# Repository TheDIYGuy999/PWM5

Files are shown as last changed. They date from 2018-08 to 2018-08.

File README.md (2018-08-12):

# This is an Arduino "PWM5" Solar Charge Controller

It was originally invented by Julian Ilett: https://www.youtube.com/watch?v=AobcNhLG_Xw&list=PLjzGSu1yGFjWa5BEHgX5UUrSexppett3W

This Arduino version uses a similar layout as arduined.eu: https://www.arduined.eu/arduino-solar-charge-controller/

After I designed and built a couple of own MPPT solar chargers (see my other Repositories here), I wanted to try this "classic" PWM design.
It works fine, but of course you can't use it for nominal voltages below 12V (or at least it would be very inefficient in this case). Check out the included PCB files, if you want to build your own PWM5 controller.

## Features / Improvements:
- Programmable with Arduino IDE
- Input voltage 12 - 22V (36 cell solar panel)
- Output voltage 10.8 - 14.4V (6 cell 12V lead acid battery)
- Suitable for solar palels up to 100W (according to Julian Ilett)
- Using the 3.3V, 8MHz Arduino Pro Mini, which requires about 5mA (instead of 20mA for the 5V, 16MHz version)
- IRLZ44N logic level MOSFET used, because the charge pump can't deliver enough voltage with 3.3V supply
- Working frequencies: 15kHz (charge pump), 2kHz (PWM)
- Structurized the software, added serial output, improved the LED to be similar with Julians design
- Readings and calculations are based on vcc, which is read automatically
- Much simpler differential control algorithm
- Schematic better structurized, easier to understand
- Minor component value changes
- Eagle schematic and board file available
- Gerber files available (allows you to order your own boards easily)
- This controller is COMMON NEGATIVE
- An anti backfeed diode on the solar panel side is required

New in V 1.0:
- Initial commit, tested with my 10W and 20W solar panels, charging my 12V, 6.6Ah Lead Acid Gel battery

## Usage

See pictures
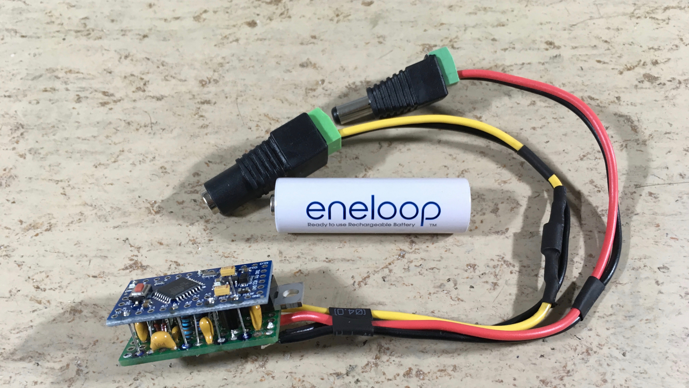
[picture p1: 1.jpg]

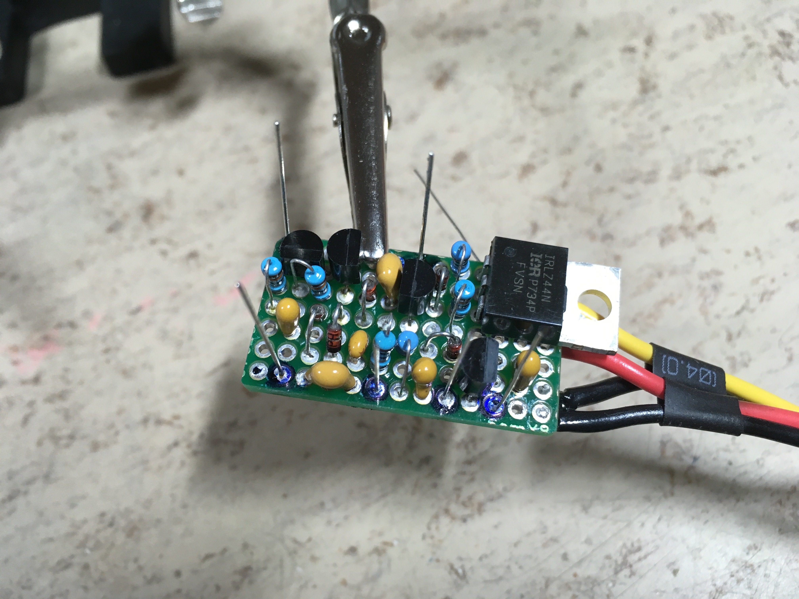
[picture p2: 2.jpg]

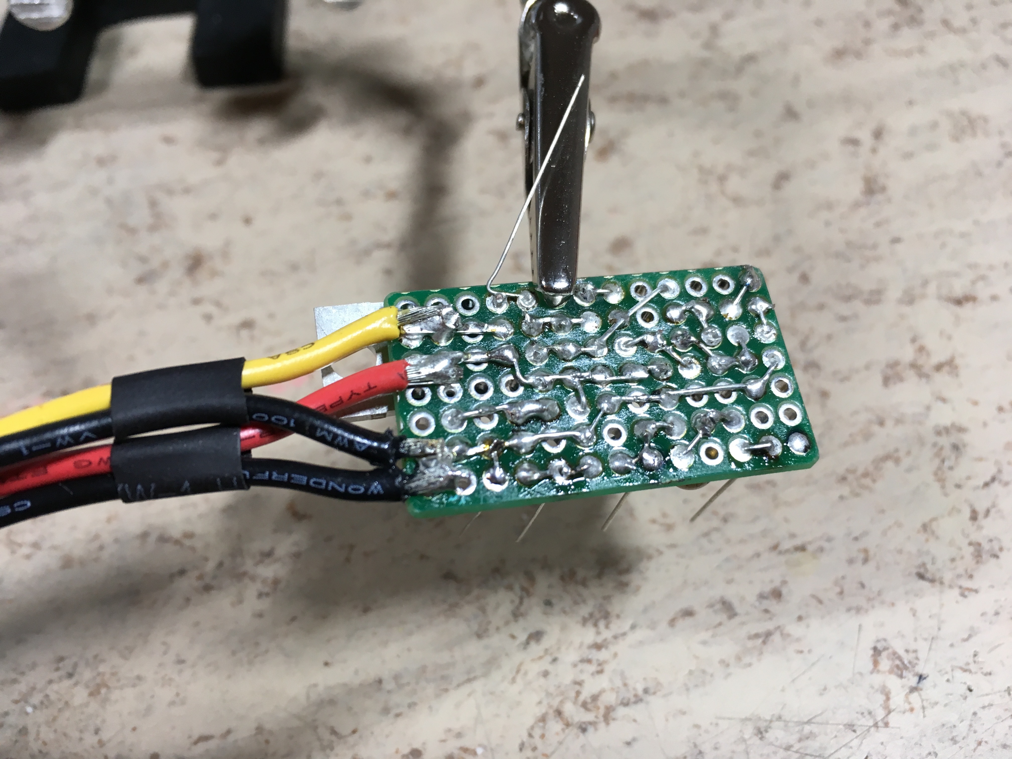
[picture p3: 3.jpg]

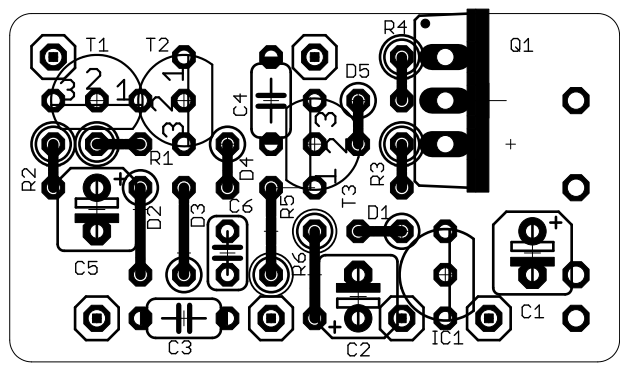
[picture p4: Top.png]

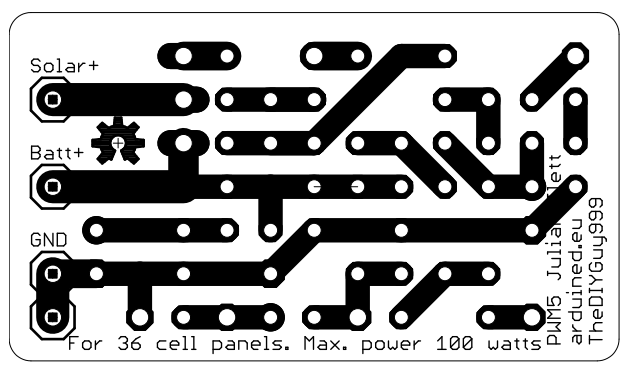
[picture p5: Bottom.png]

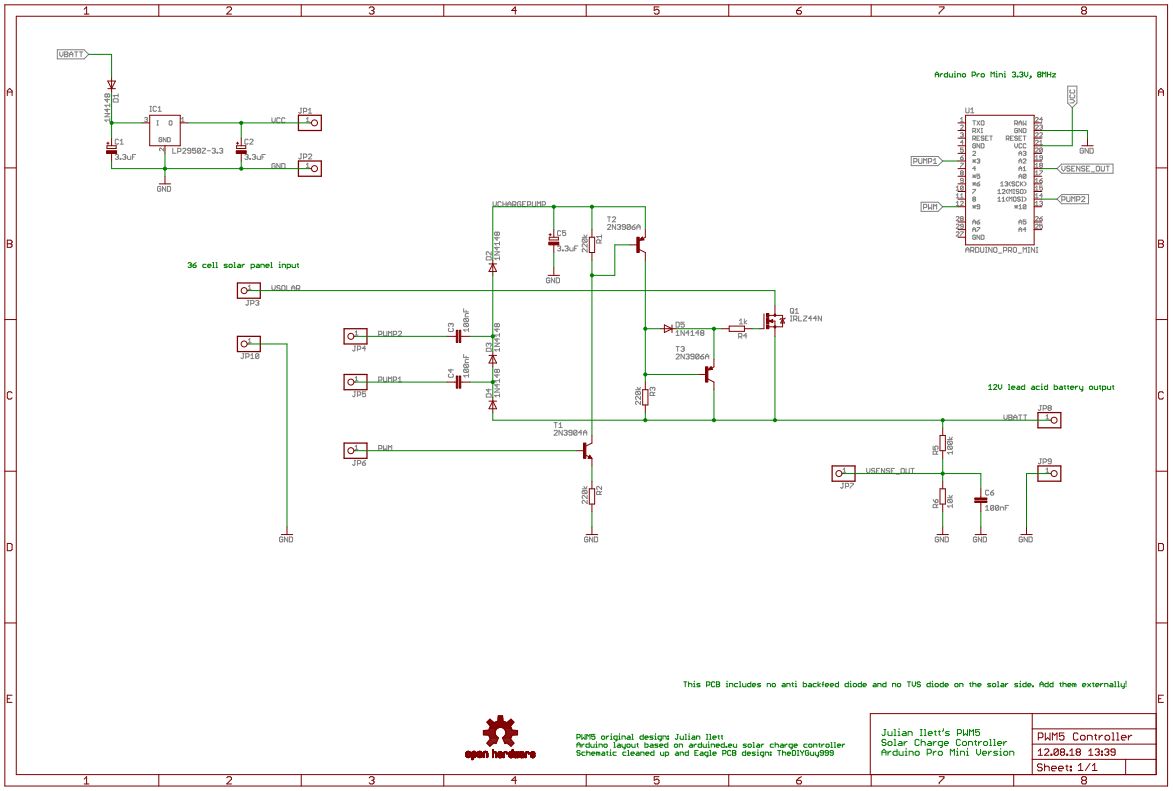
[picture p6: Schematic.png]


Also have a look at the pdf schematic.

(c) 2018 TheDIYGuy999

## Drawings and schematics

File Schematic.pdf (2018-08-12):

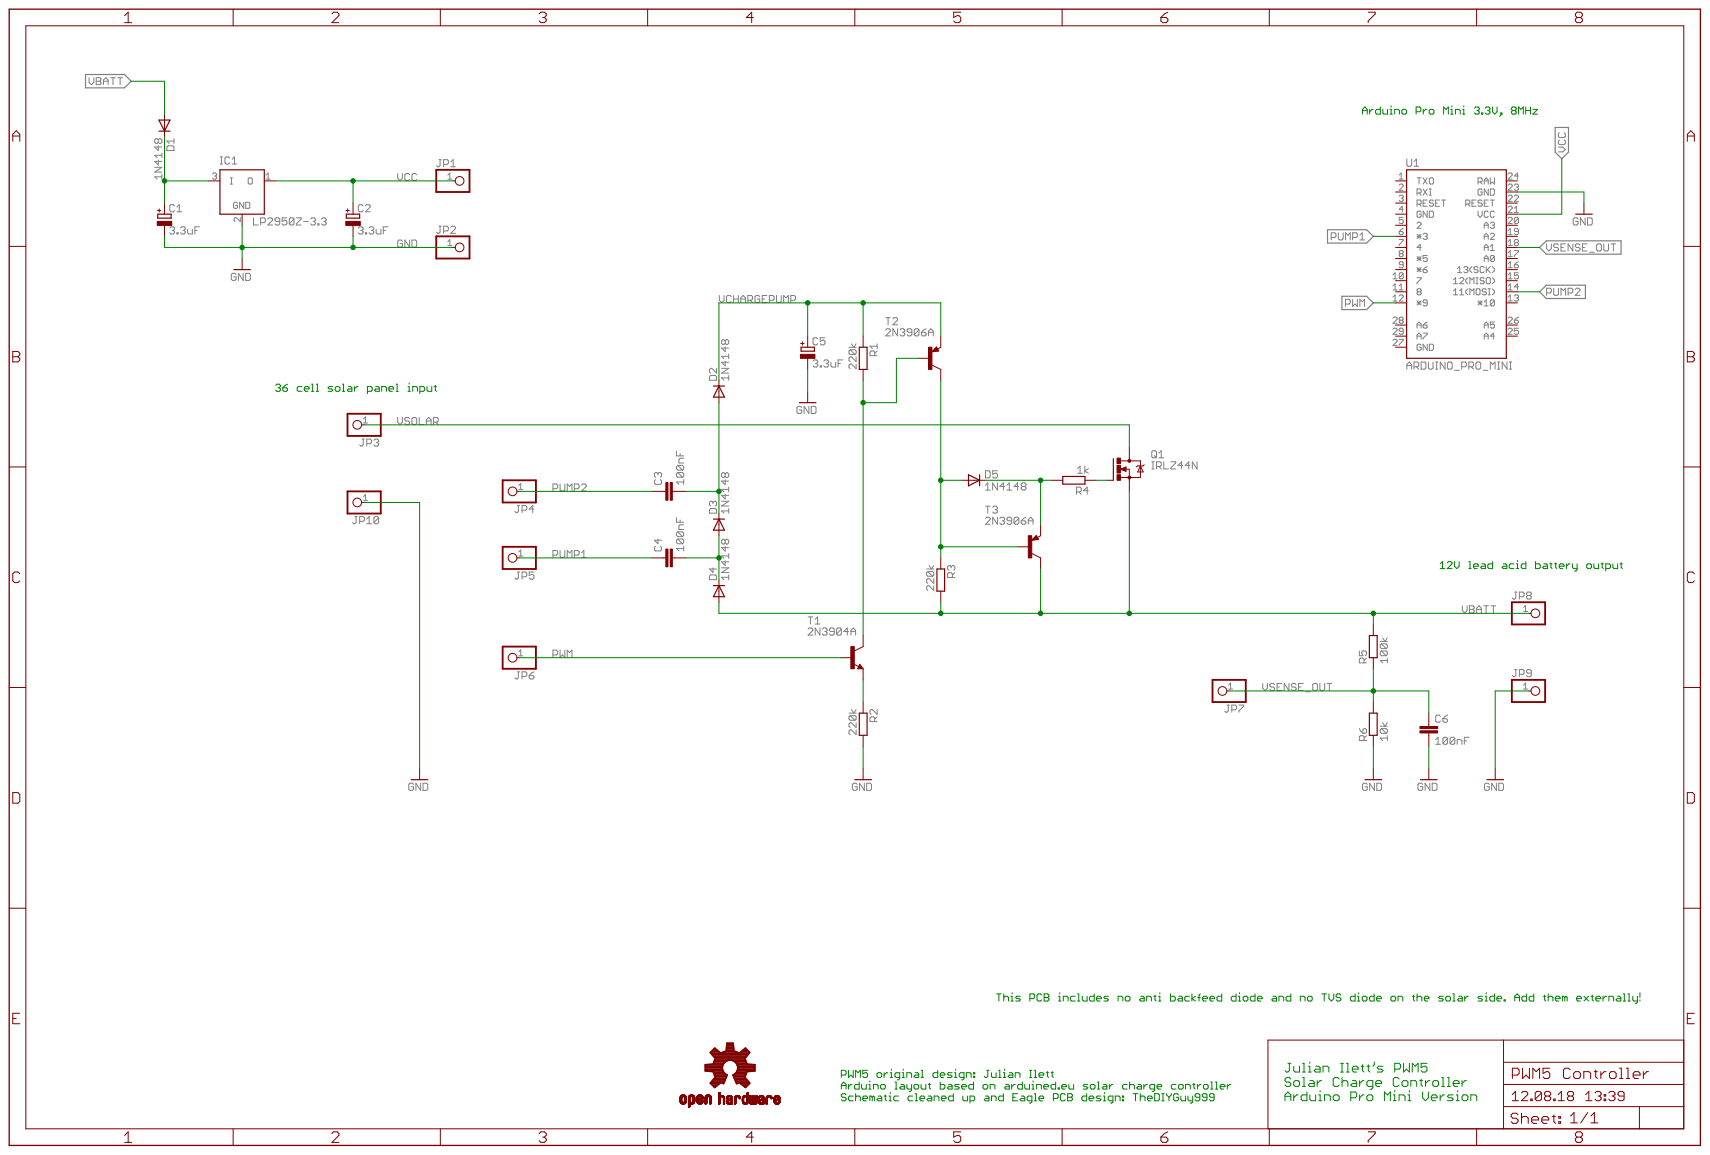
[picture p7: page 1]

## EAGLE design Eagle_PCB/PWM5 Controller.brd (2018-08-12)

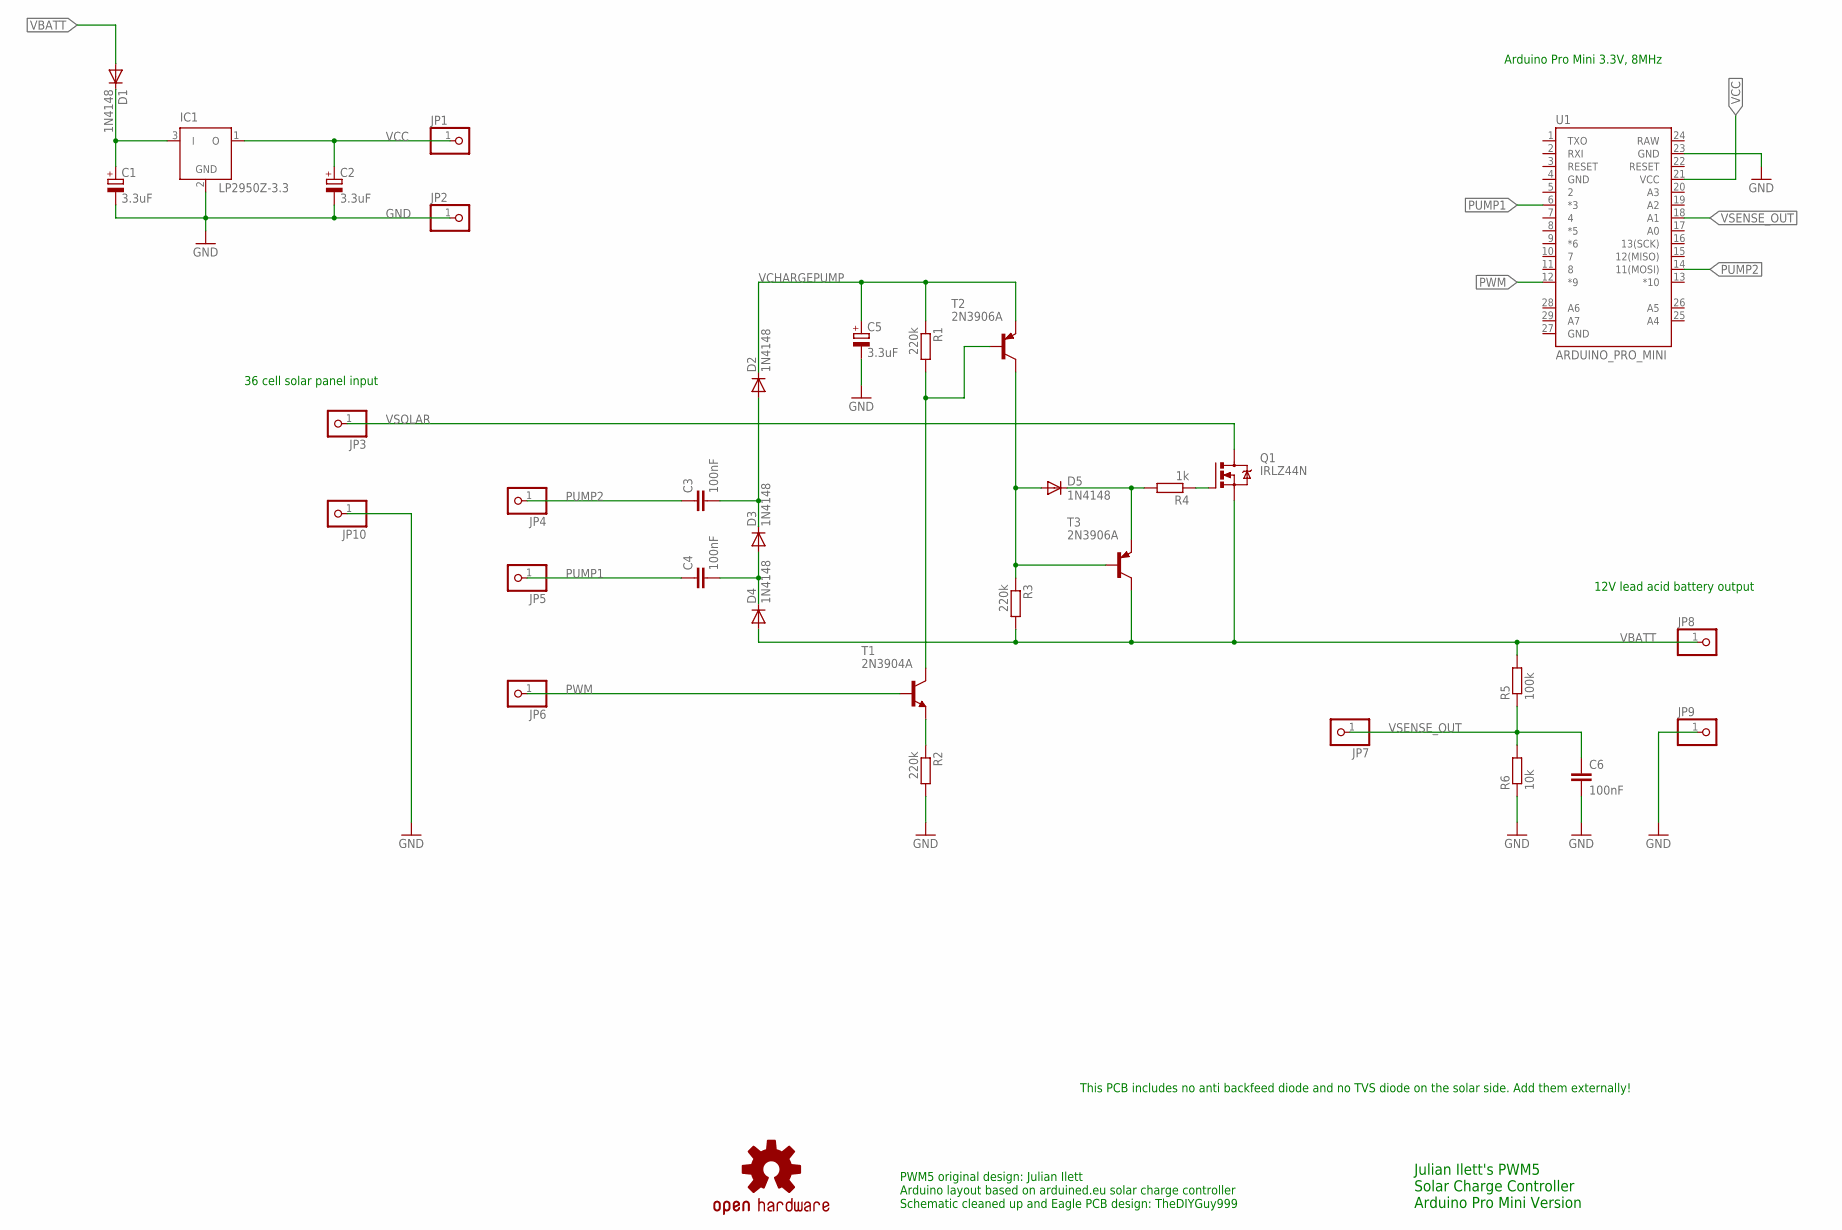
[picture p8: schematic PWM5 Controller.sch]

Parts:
C1, C2, C5: 3.3uF; B45181A
C3, C4: 100nF; C050-024X044
C6: 100nF; C025-024X044
D1, D4, D5: 1N4148; DO35-V
D2, D3: 1N4148; DO35-V2
IC1: LP2950Z-3.3; TO92-AMMOPACK
JP1, JP2, JP3, JP4, JP5, JP6, JP7, JP8, JP9, JP10: PINHD-1X1; 1X01
LOGO1: OSHW-LOGOS; OSHW-LOGO-S
Q1: IRLZ44N; TO220BV
R1, R2, R3: 220k; 0207/2V
R4: 1k; 0207/2V
R5: 100k; 0207/5V
R6: 10k; 0207/5V
T1: 2N3904A; TO92-AMMOPACK
T2, T3: 2N3906A; TO92-AMMOPACK
U1: ARDUINO_PRO_MINI

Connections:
GND: C1.-, C2.-, C5.-, C6.2, IC1.2 (GND), JP2.1, JP9.1, JP10.1, R2.2, R6.1, U1.23 (GND)
unnamed: D5.C, R4.2, T3.3 (E)
unnamed: Q1.G, R4.1
unnamed: C1.+, D1.C, IC1.3 (I)
unnamed: R2.1, T1.3 (E)
unnamed: D5.A, R3.1, T2.1 (C), T3.2 (B)
unnamed: R1.2, T1.1 (C), T2.2 (B)
unnamed: C4.2, D3.A, D4.C
unnamed: C3.2, D2.A, D3.C
PUMP1: C4.1, JP5.1, U1.6 (*3)
PUMP2: C3.1, JP4.1, U1.14 (11(MOSI))
PWM: JP6.1, T1.2 (B), U1.12 (*9)
VBATT: D1.A, D4.A, JP8.1, Q1.S, R3.2, R5.2, T3.1 (C)
VCC: C2.+, IC1.1 (O), JP1.1, U1.21 (VCC)
VCHARGEPUMP: C5.+, D2.C, R1.1, T2.3 (E)
VSENSE_OUT: C6.1, JP7.1, R5.1, R6.2, U1.18 (A1)
VSOLAR: JP3.1, Q1.D

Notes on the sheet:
Julian Ilett's PWM5 Solar Charge Controller Arduino Pro Mini Version
PWM5 original design: Julian Ilett Arduino layout based on arduined.eu solar charge controller Schematic cleaned up and Eagle PCB design: TheDIYGuy999
This PCB includes no anti backfeed diode and no TVS diode on the solar side. Add them externally!
Arduino Pro Mini 3.3V, 8MHz
36 cell solar panel input
12V lead acid battery output

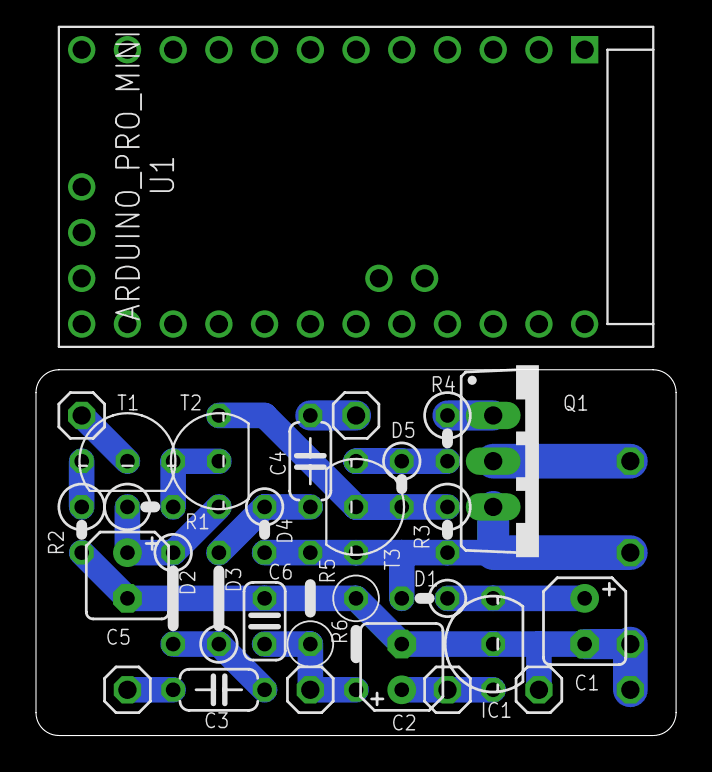
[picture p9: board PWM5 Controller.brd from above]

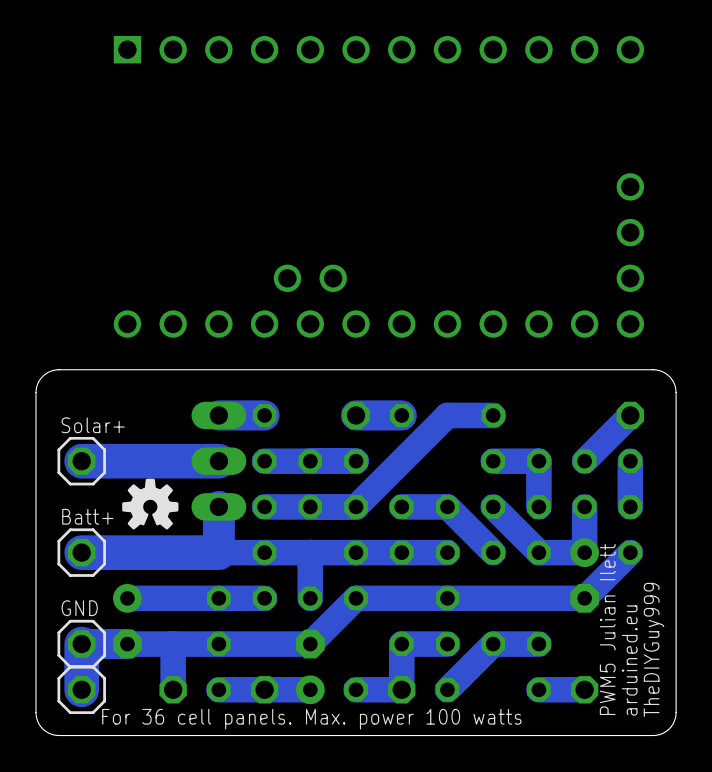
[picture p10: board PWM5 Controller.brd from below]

Board: 2 copper layers, 35.6 x 20.3 mm, 34 parts (5 on the bottom side), 17 nets.

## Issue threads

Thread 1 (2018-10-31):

Odd PWM Waveform on MOSFET Gate Pin

jmd13391, 2018-10-31:
Hi TheDIYGuy999 !! Thank you for your excellent work on this PWM5 variant. I have taken your design and attempted to adopt it for use with a 24v,18Ah battery and a 37v, 70w solar panel. Although I am using a different MCU, all discrete components are as you call-out in the original schematic with the exception of the voltage divider resistors R5 & R6 (47K, 5.6K) and C5 (10uF). Here is my question / issue:

I am seeing an odd "inverted shark fin" PWM waveform at the MOSFET gate and was hoping that you might have insight as to how to correct it. See photo. CH1 (yellow) is the PWM waveform from the MCU. CH2 (blue) is the PWM waveform at the MOSFET gate.

MCU PWM Freq. = 300Hz. (MCU max is 1KHz.)
MCU Charge Pump Freq: 4.14KHz. (this is the MCU max)

Thank you in advance...

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

TheDIYGuy999, 2018-10-31:
Hi,
Looks like the mosfet gate is not discharged fast enough. This is a potential issue of Julians gate driver circuitry. T3 provides a fast discharge path, but does not work at low voltages, because of the D5 voltage drop. That's why the voltage starts dropping fast and then slow.
The charge pump frequency may also be too low for a stable gate supply. Have you confirmed the stability of this rail with the scope? I assume, you have used a bigger C5 because of this potential issue.
Also make sure, that you don't exceed the gate and base voltage limits of your transistors, because of your high voltages.

jmd13391, 2018-10-31:
Hi TheDIYGuy999, Thank you for your prompt reply.

> "T3 provides a fast discharge path, but does not work at low voltages, because of the D5 voltage drop."

Would replacing D5 (1N4148) with a lower voltage drop Schottky diode improve the discharge rate?

> "The charge pump frequency may also be too low for a stable gate supply."

I had a typo in my original post... the Charge Pump pulse frequency of each square wave is ~4.14Khz., CP1 pulse & CP2 pulse waves are 180 degrees out of phase with a 10uS state change delay:

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

> "Have you confirmed the stability of this rail with the scope?"

Yes. Rock solid at 29.1v under the following conditions - Battery: 26.81v, Solar Panel: 33.52v

> "I assume, you have used a bigger C5 because of this potential issue."

Yes, Sir. ;-)

Do you have any suggestions as to how the circuit can be modified so as to improve the trailing edge of the MOSFET gate pulse?

Thank you again for your assistance with this issue...

jmd13391, 2018-11-13:
Closing due to inactivity.

Closed 2018-11-13.

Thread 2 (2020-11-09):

Board size for Gerbers.zip? JLPCB asks that :-7

Meins321, 2020-11-09:
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
JLPCB asks for the board size of the gerber files...

BTW to you have one or two boards? i would like to build one and try charging a 12V lead acid with it :+1:

TheDIYGuy999, 2020-11-11:
You don't need to add the size, just upload the updated Gerbers.zip. Then it should look like this:
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

No, I don't have boards, I just made one on veröffentlicht board

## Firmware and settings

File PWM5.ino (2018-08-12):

/* This PWM solar charge controller is based on:
    Julian Itett's PWM5: https://www.youtube.com/watch?v=AobcNhLG_Xw&list=PLjzGSu1yGFjWa5BEHgX5UUrSexppett3W
    arduined.eu's PWM solar charge controller: https://www.arduined.eu/arduino-solar-charge-controller/

    Changes and improvements, implemented by TheDIYGuy999:
    - Using the 3.3V, 8MHz Arduino Pro Mini, which requires about 5mA (instead of 20mA for the 5V, 16MHz version)
    - IRLZ44N logic level MOSFET used, because the charge pump can't deliver enough voltage with 3.3V supply
    - Structurized the software, added serial output, improved the LED to be similar with Julians design
    - Readings and calculations are based on vcc, which is read automatically
    - Much simpler differential control algorithm
    - Schematic better structurized, easier to understand
    - Minor component value changes
    - Eagle schematic and board file available
    - Gerber files available (allows you to order your own boards easily)
*/

const float codeVersion = 1.0; // Software revision

//
// =======================================================================================================
// BUILD OPTIONS (comment out unneeded options)
// =======================================================================================================
//

#define DEBUG // if not commented out, Serial.print() is active! For debugging only!!

//
// =======================================================================================================
// INCLUDE LIRBARIES
// =======================================================================================================
//

// Tabs (header files in sketch directory)
#include "readVCC.h"

// Libraries
#include <statusLED.h> // TheDIYGuy999 library: https://github.com/TheDIYGuy999/statusLED

//
// =======================================================================================================
// PIN ASSIGNMENTS & GLOBAL VARIABLES
// =======================================================================================================
//

// Pins
#define PWM 9
#define PUMP1 3
#define PUMP2 11
#define VSENSE_OUT A1

// Status LED objects
statusLED LED(false); // false = not inversed (LED wired between GND and output)

float outputVoltage;
float vcc = 3.3; // Init value only. Will be read automatically later on. Base for all our voltage readings!
float pwm; // float required for finer granularity during calculation in differential equations!

// Configuration variables (you may have to change them)
float targetOutputVoltage = 13.8; // Our maximum battery charge voltage
float voltageCalibration = 94.7; // (100k + 10k) / 10k = 11  ->  1024 / 11 = 93.09 in theory

//
// =======================================================================================================
// MAIN ARDUINO SETUP (1x during startup)
// =======================================================================================================
//

void setup() {

  // Serial port setup
#ifdef DEBUG
  Serial.begin(19200);
#endif

  // Output setup
  pinMode(PWM, OUTPUT);
  pinMode(PUMP1, OUTPUT);
  pinMode(PUMP2, OUTPUT);

  // PWM setup
  TCCR2A = TCCR2A | B00110000; // Inverting mode for charge pump
  TCCR2B = TCCR2B & B11111000 | B001; // Charge pump pins 15kHz
  TCCR1B = TCCR1B & B11111000 | B010; // PWM 1.95kHz (the maximum of this MOSFET driver circuit!)

  analogWrite(PUMP2, 117); // 117
  analogWrite(PUMP1, 137); // 137

  LED.begin(13); // Onboard LED on pin 13
}

//
// =======================================================================================================
// LED
// =======================================================================================================
//

void led() {
  if (pwm == 255) {
    // Indicate battery voltage: 13 flashes = 13V etc.
    LED.flash(20, 380, 700, outputVoltage); // ON, OFF, PAUSE, PULSES
  }

  // Indicate pwm
  else LED.flash((pwm / 2), 128 - (pwm / 2), 0, 0); // ON, OFF, PAUSE, PULSES
}

//
// =======================================================================================================
// CHECK VCC VOLTAGE
// =======================================================================================================
//

void checkVcc(boolean immediately) {

  static unsigned long lastVcc;
  if (millis() - lastVcc >= 200 || immediately) { // Every 200ms or immediately
    lastVcc = millis();
    vcc = readVcc() / 1000.0;
  }
}

//
// =======================================================================================================
// READ SENSORS
// =======================================================================================================
//

void readSensors() {
  outputVoltage = analogRead(VSENSE_OUT) * vcc / voltageCalibration;
}

//
// =======================================================================================================
// CONTROL LOOP
// =======================================================================================================
//

void controlLoop() {
  pwm += targetOutputVoltage - outputVoltage; // simple p (differential) controller
  pwm = constrain(pwm, 0, 255 );
  analogWrite(PWM, pwm);
}

//
// =======================================================================================================
// SERIAL PRINT
// =======================================================================================================
//
void serialPrint() {
#ifdef DEBUG
  static unsigned long lastPrint;
  if (millis() - lastPrint >= 1000) { // Every 1000ms
    lastPrint = millis();

    Serial.print("Setpoint: ");
    Serial.print(targetOutputVoltage);

    Serial.print(" Battery: ");
    Serial.print(outputVoltage);

    Serial.print(" PWM: ");
    Serial.print(pwm, 0);

    Serial.print(" vcc: ");
    Serial.println(vcc);
  }
#endif
}

//
// =======================================================================================================
// MAIN LOOP
// =======================================================================================================
//

void loop() {

  checkVcc(false); // with delay
  readSensors();
  controlLoop();
  led();
  serialPrint();
}

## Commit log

2018-08-12 V1.0: Initial commit
    [PWM5 Controller.brd, PWM5 Controller.sch]
2020-11-11 Gerber file replaced

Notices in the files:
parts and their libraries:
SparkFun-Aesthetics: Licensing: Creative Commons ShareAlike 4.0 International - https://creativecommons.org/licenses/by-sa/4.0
